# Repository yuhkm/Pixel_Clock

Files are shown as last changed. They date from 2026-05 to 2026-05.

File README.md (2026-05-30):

# PixelClock

An ESP32-S3 smart desk clock based on a NeoPixel LED matrix.
A personal project with self-designed PCB, enclosure CAD, and firmware.

---

<p align="center">
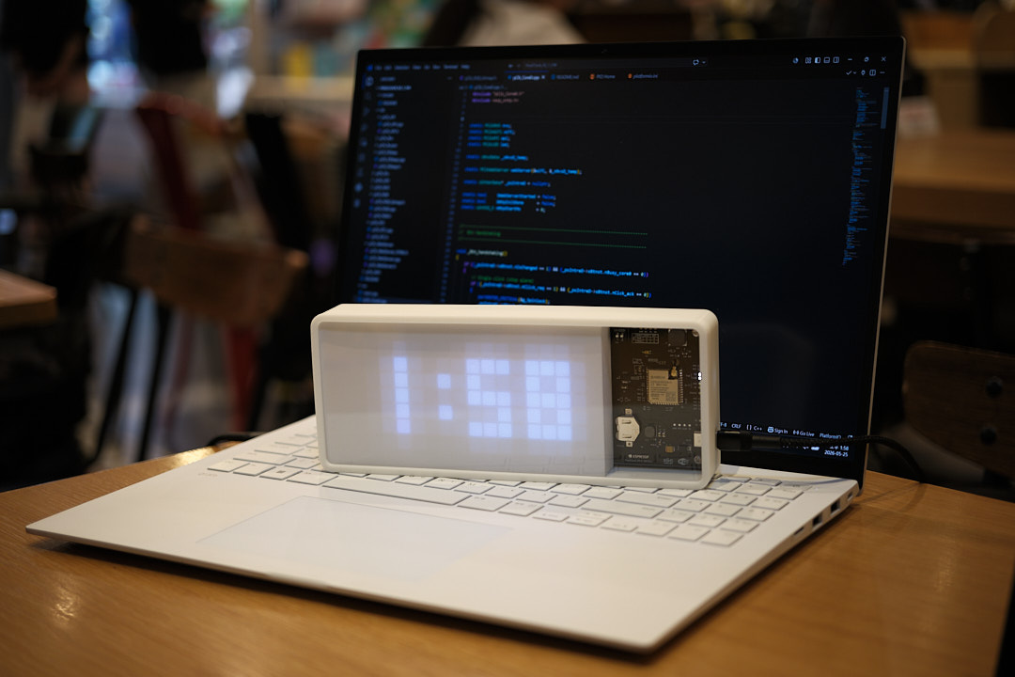
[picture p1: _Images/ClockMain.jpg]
  
  
</p>

<!-- Demo GIF -->
<!-- ![Demo](docs/images/demo.gif) -->

---

## Features

- **Clock** — Automatic NTP time sync, PCF85063A hardware RTC
- **Weather** — KMA ultra-short-term forecast API, displays temperature / sky condition / precipitation
- **Alarm** — Day-of-week repeat alarm with melody and volume control
- **Night Mode** — Auto brightness adjustment via illuminance sensor
- **Sleep Mode** — Auto deep sleep during configured hours, wakes via RTC interrupt
- **Web Setup** — Full configuration through a browser in AP mode

---

## Repository Structure

```
PixelClock/
├── CAD/
│   ├── Type_A/                Enclosure Type A design files
│   └── Type_B/                Enclosure Type B design files
├── FW/
│   ├── src/
│   │   ├── main.cpp           Task creation and entry point
│   │   ├── pClk_Core0.cpp     Core0 state machine (WiFi / NTP / API / Web server)
│   │   └── pClk_Core1.cpp     Core1 state machine (Display / RTC / Alarm)
│   ├── lib/
│   │   ├── pClk_API/          KMA weather API
│   │   ├── pClk_Btn/          Button (click / 3s hold / 10s hold)
│   │   ├── pClk_Buzzer/       Buzzer (beep / melody)
│   │   ├── pClk_DSleep/       Deep sleep entry / wake
│   │   ├── pClk_Illu/         Illuminance sensor ADC
│   │   ├── pClk_LED/          Indicator LEDs
│   │   ├── pClk_NVS/          NVS save / load with CRC verification
│   │   ├── pClk_RGB/          NeoPixel rendering (clock / weather / scroll)
│   │   ├── pClk_RTC/          PCF85063A I2C driver
│   │   ├── pClk_WebServer/    AP setup web server
│   │   └── pClk_WiFi/         WiFi AP / STA management
│   └── include/
│       ├── pClk_config.h      GPIO pin map and parameters
│       └── pClk_gData.h       Inter-core shared data structures
└── PCB/
    ├── Gerber/                Gerber files
    └── SMT/                   SMT files
```

---

## Bill of Materials (BOM)

| Component | Model / Spec |
|---|---|
| MCU | ESPRESSIF ESP32-S3 WROOM-1U N16R8 |
| NeoPixel Matrix | WS2812B 8×8 module × 2 |
| RTC | PCF85063ATT |
| RTC Backup Battery | CR1220 |
| Buzzer | BMB-2703N |
| Illuminance Sensor | TEMT6000 |
| Regulator | AP63203WU |
| Power Connector | USB Type-C |

---

## Hardware

### PCB

| Item | Spec |
|---|---|
| Size | 63×80mm |
| Layers | 4 |
| Design Files | [PCB/](PCB/) |

### Enclosure

| Type | Size | Design Files |
|---|---|---|
| Type A | 217×88×32mm | [CAD/Type_A/](CAD/Type_A/) |
| Type B | 173×88×38mm | [CAD/Type_B/](CAD/Type_B/) |

---

## Software

### Architecture

Runs on FreeRTOS dual-core. Core0 handles networking, Core1 handles display and sensors.

| Core | Role |
|---|---|
| Core 0 | WiFi / NTP / Weather API / Web server |
| Core 1 | NeoPixel matrix / RTC / Illuminance sensor / Button / Buzzer |

---

## Build

**Requirements:** [PlatformIO](https://platformio.org/)

```bash
# Clone the repository
git clone https://github.com/yuhkm/Pixel_Clock.git
cd PixelClock/FW

# Build and upload
pio run --target upload

# Serial monitor
pio device monitor --baud 115200
```

---

## Setup

### Weather API Key Required

To use the weather feature, a **KMA Ultra-Short-Term Forecast API** key is required.

- Get a key: [Korea Public Data Portal - KMA Forecast API](https://www.data.go.kr/data/15084084/openapi.do)
- Enter the key in the API Key field on the setup page

### Setup
1. Hold the button for **3 seconds** to enter setup mode (2 beeps)
2. Connect to the **`PixelClock`** Wi-Fi AP
3. Open **`setup.local`** in a browser
4. Configure WiFi, weather API key, alarm, and display settings, then save
5. Device reboots and applies settings automatically

<p align="center">
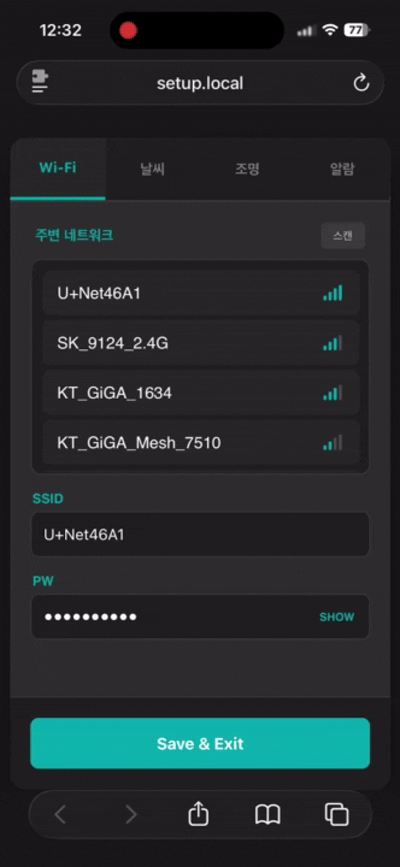
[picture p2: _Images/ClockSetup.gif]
  
</p>

### Factory Reset

Hold the button for **10 seconds** to clear all NVS settings and re-enter setup mode.

---

## Serial Log

Serial monitor format (115200 baud): `>>> [Module][Function] message`

| Tag | Description |
|-----|---|
| `[Core0][BOOT]` | NVS config valid / invalid on boot |
| `[Core0][SETUP]` | Web server started |
| `[Core0][APPLY]` | Config saved, rebooting |
| `[Core0][RESET]` | Factory reset |
| `[WiFi][STA]` | STA connecting / success / failed |
| `[WiFi][AP]` | AP setup complete |
| `[NTP][NTP]` | NTP initialized / received / timeout |
| `[Weather][API]` | Updated / Failed with HTTP code / Parse error |
| `[WEB][HTTP]` | Web server started |
| `[Core1][NVS]` | Settings applied |
| `[Core1][RTC]` | NTP → RTC sync |
| `[Core1][ALARM]` | Alarm fired / auto-stopped |
| `[Core1][ILLU]` | Night mode ON / OFF |
| `[NVS][CRC]` | CRC mismatch (settings cleared) |
| `[RTC][I2C]` | I2C init failed |
| `[DSleep][RTC]` | Entering deep sleep, wake time |

---

## License

[MIT License](LICENSE)

Copyright (c) 2026 <!-- name or GitHub username -->

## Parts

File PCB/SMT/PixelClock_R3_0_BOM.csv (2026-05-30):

Comment | Designator | Footprint
CR1220 | B1 | LIB_CR1220_SMD:LIB_CR1220_SMD
Buzzer | BZ1 | Buzzer_Beeper:MagneticBuzzer_CUI_CMT-8504-100-SMT
100uF(T) | C1 | Capacitor_Tantalum_SMD:CP_EIA-3528-21_Kemet-B
100nF(0402) | C2,C7,C8,C10,C11 | Capacitor_SMD:C_0402_1005Metric
22uF(0805) | C3,C4 | Capacitor_SMD:C_0805_2012Metric
10uF(0805) | C5,C6 | Capacitor_SMD:C_0805_2012Metric
1uF(0603) | C9 | Capacitor_SMD:C_0603_1608Metric
TVS | D1 | Diode_SMD:D_SMB
RB521S30T1G | D2,D3,D4 | Diode_SMD:D_SOD-523
USB_C_Receptacle_USB2.0_16P | J1 | Connector_USB:USB_C_Receptacle_GCT_USB4085
Conn_01x04_Pin | J2 | Connector_PinHeader_2.54mm:PinHeader_1x04_P2.54mm_Vertical
Molex_5268-03_F | J3,J4,J5 | Connector_Molex:Molex_SPOX_5267-03A_1x03_P2.50mm_Vertical
3.9uH | L1 | Inductor_SMD:L_APV_ANR6020
LED_Y | L2,L3,L4,L5,L6,L7 | LED_SMD:LED_0603_1608Metric
SS8050 | Q1 | Package_TO_SOT_SMD:SOT-23
5.1kR(0402) | R1,R2 | Resistor_SMD:R_0402_1005Metric
10kR(0402) | R3,R4,R5,R6,R7,R8,R9,R15,R19,R26 | Resistor_SMD:R_0402_1005Metric
22R(0402) | R10,R11 | Resistor_SMD:R_0402_1005Metric
4.7kR(0402) | R12,R13,R14 | Resistor_SMD:R_0402_1005Metric
1kR(0603) | R16,R17,R18,R20,R23,R24,R25 | Resistor_SMD:R_0603_1608Metric
SW_DIP_x02 | SW1 | Button_Switch_THT:SW_DIP_SPSTx02_Slide_6.7x6.64mm_W7.62mm_P2.54mm_LowProfile
SW_Push | SW2 | Button_Switch_THT:SW_PUSH_6mm
ESP32-S3-WROOM-1 | U1 | RF_Module:ESP32-S3-WROOM-1U
AP63203WU | U2 | Package_TO_SOT_SMD:TSOT-23-6
PCF85063ATT_AJ | U3 | lumina_lib:SOP65P490X110-8N
TEMT6000 | U4 | lumina_lib:TEMT6000
Q13FC13500004 | Y1 | LIB_Q13FC13500004:Q13FC13500004FC13532768KHZ125PF

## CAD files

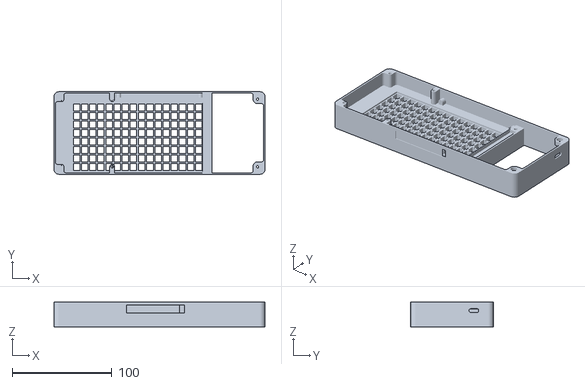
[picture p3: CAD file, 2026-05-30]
CAD/Type_A/PixelClock_Type_A_Middle.STL
212.0 x 83.0 x 25.0

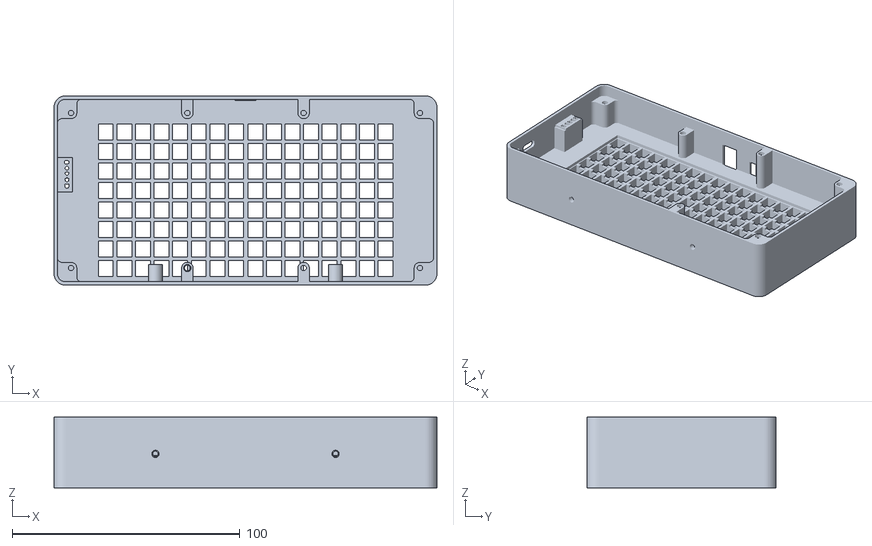
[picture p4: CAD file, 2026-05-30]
CAD/Type_B/PixelClock_Type_B_Middle.STL
168.0 x 83.0 x 31.0

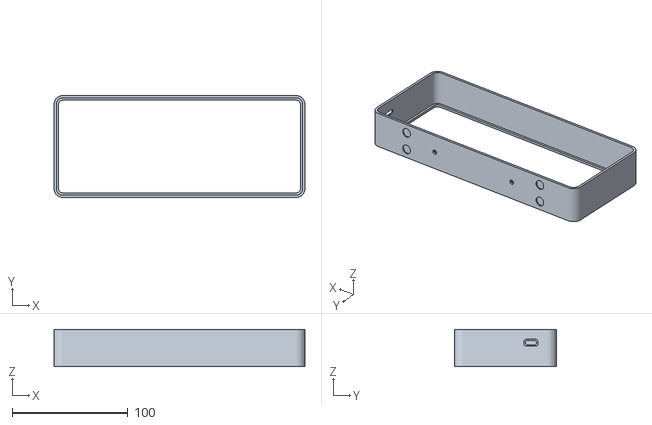
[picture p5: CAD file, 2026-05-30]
CAD/Type_A/PixelClock_Type_A_Front.STL
217.0 x 88.0 x 32.0

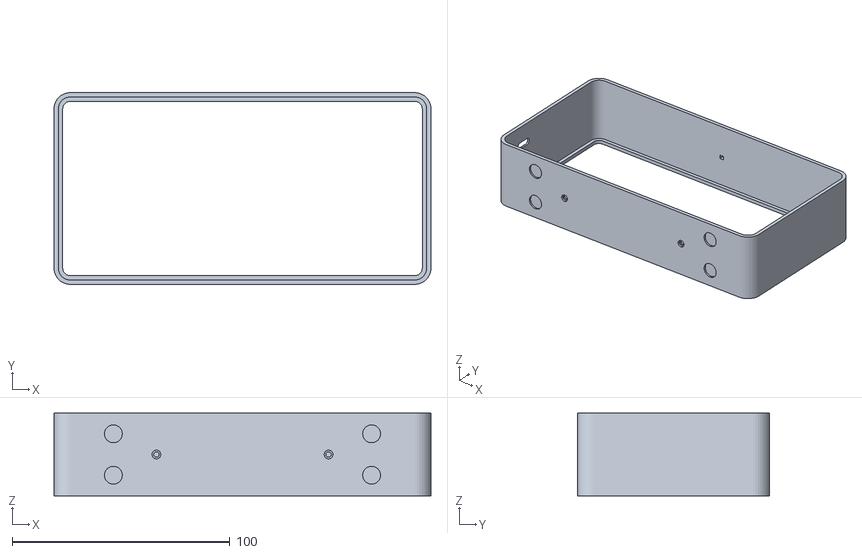
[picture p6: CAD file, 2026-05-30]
CAD/Type_B/PixelClock_Type_B_Front.STL
173.0 x 88.0 x 38.0

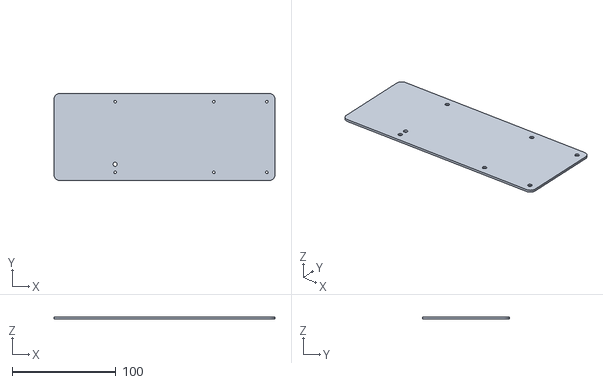
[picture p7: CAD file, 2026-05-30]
CAD/Type_A/PixelClock_Type_A_Back.STL
212.6 x 83.6 x 2.00

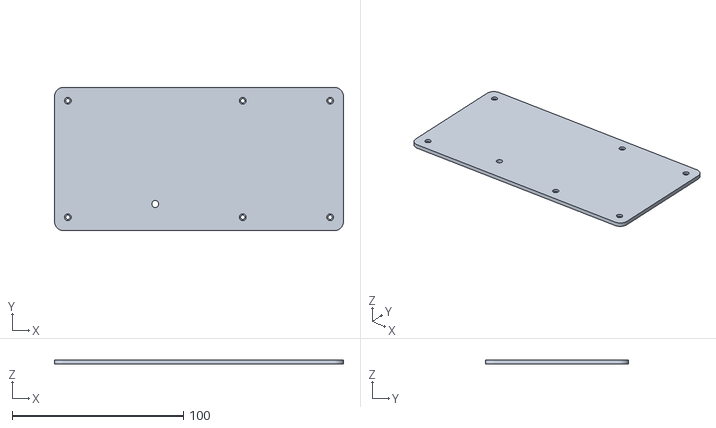
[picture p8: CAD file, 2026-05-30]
CAD/Type_B/PixelClock_Type_B_Back.STL
168.6 x 83.6 x 2.50

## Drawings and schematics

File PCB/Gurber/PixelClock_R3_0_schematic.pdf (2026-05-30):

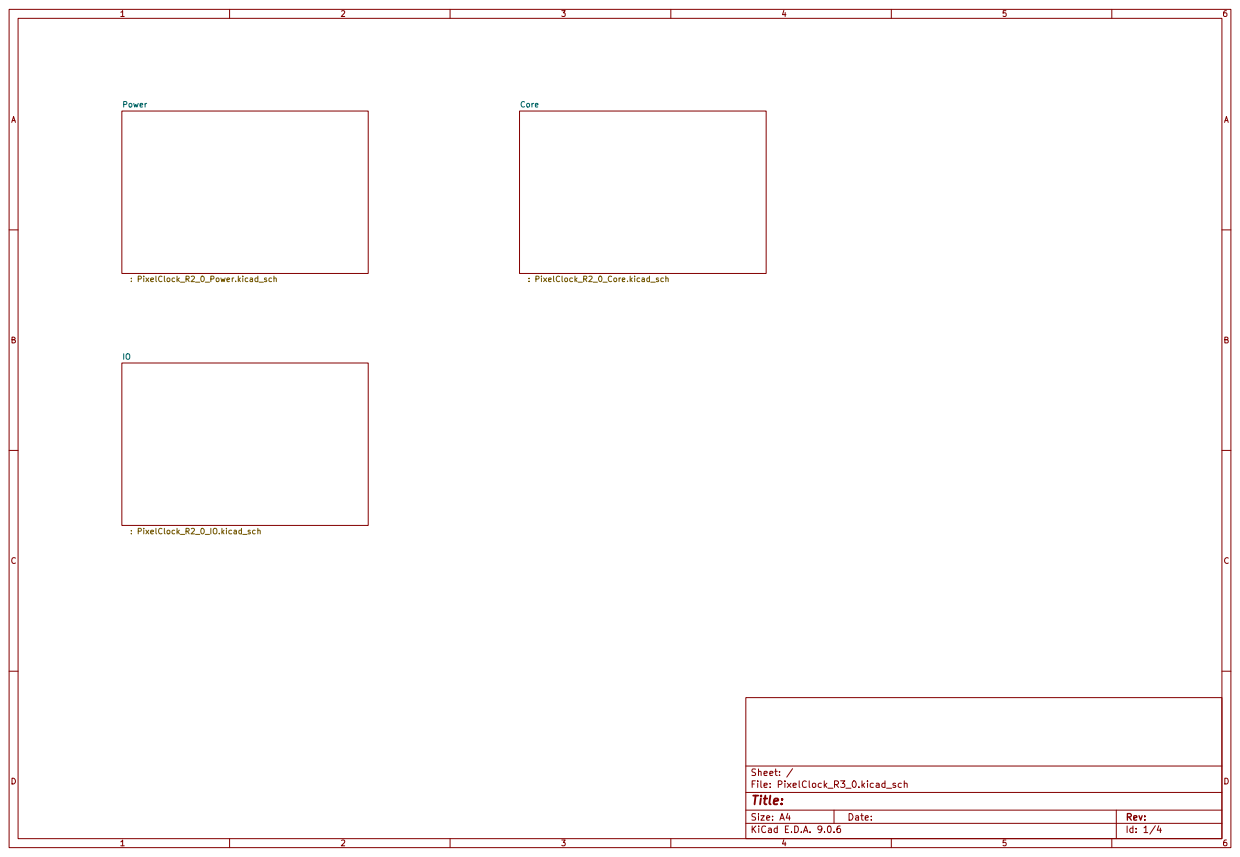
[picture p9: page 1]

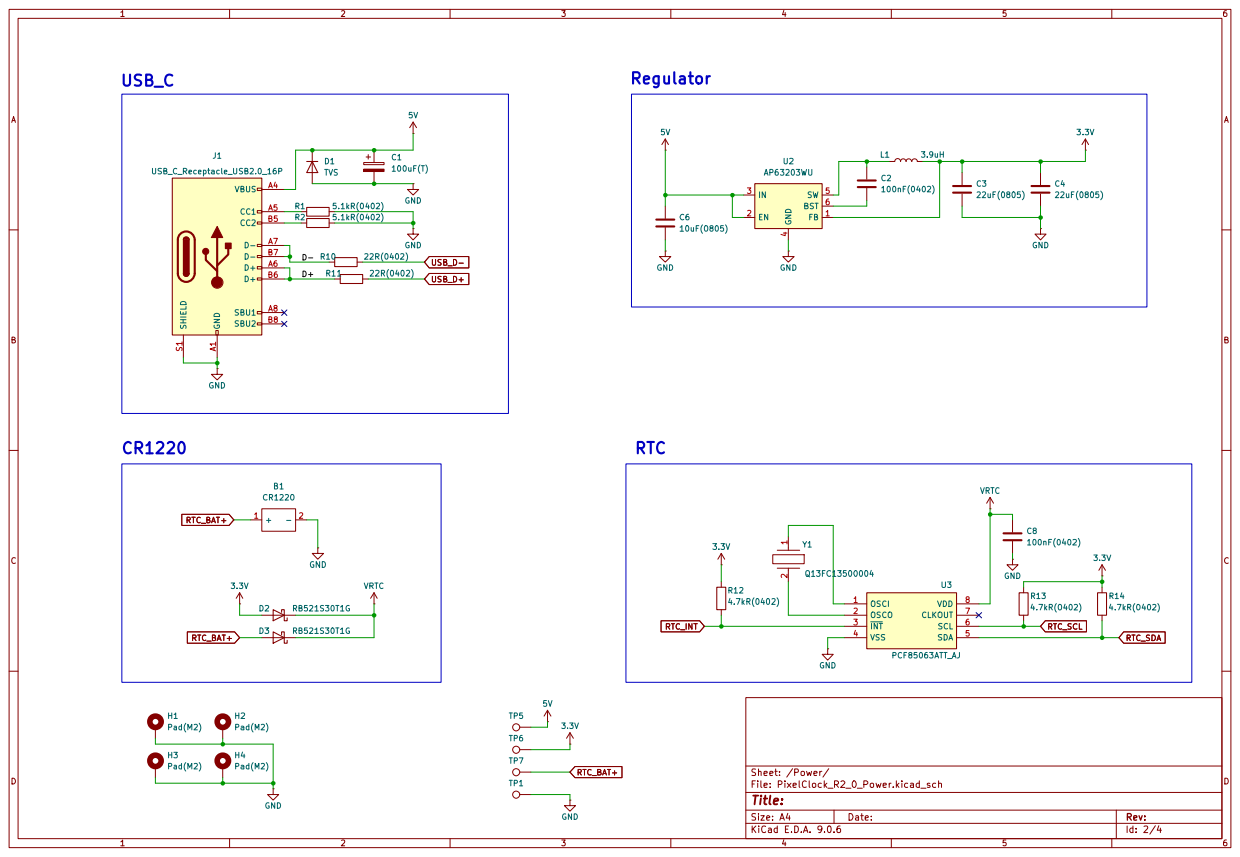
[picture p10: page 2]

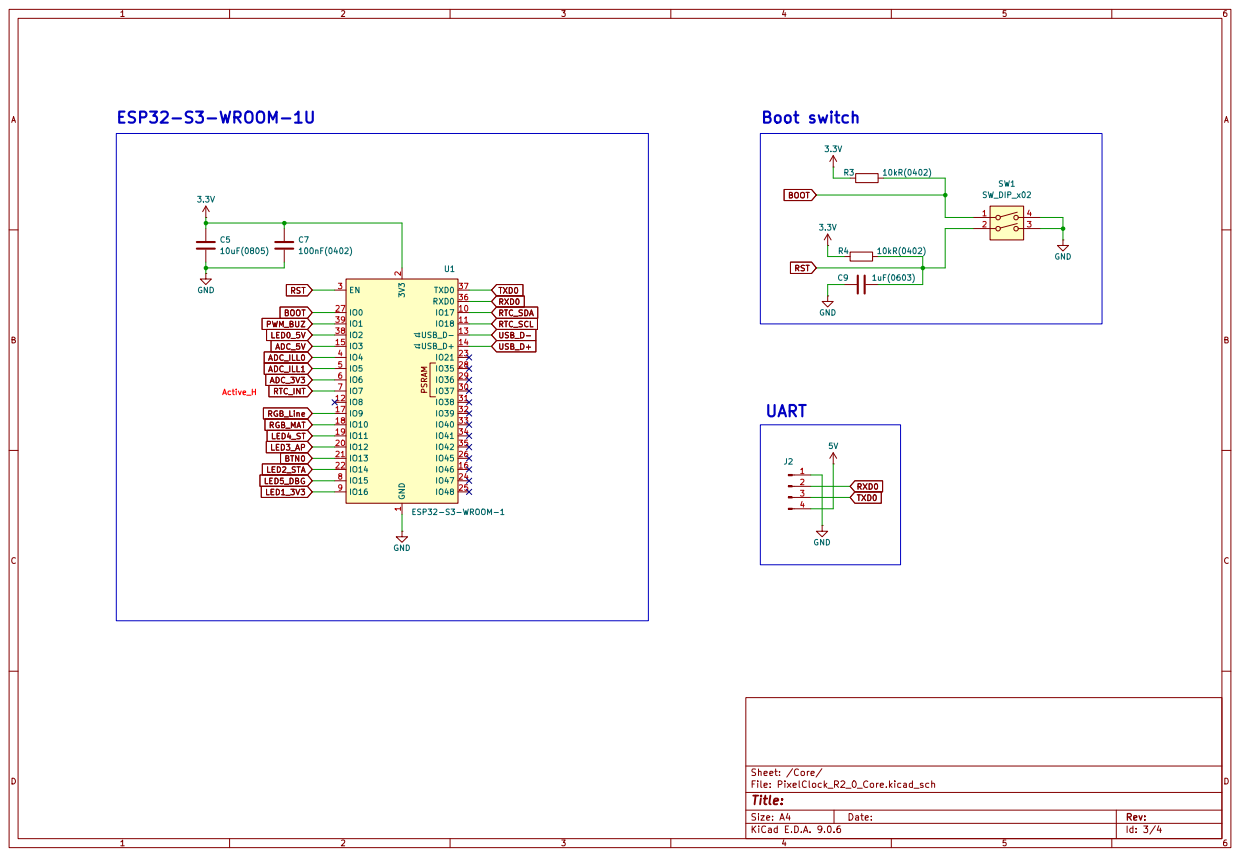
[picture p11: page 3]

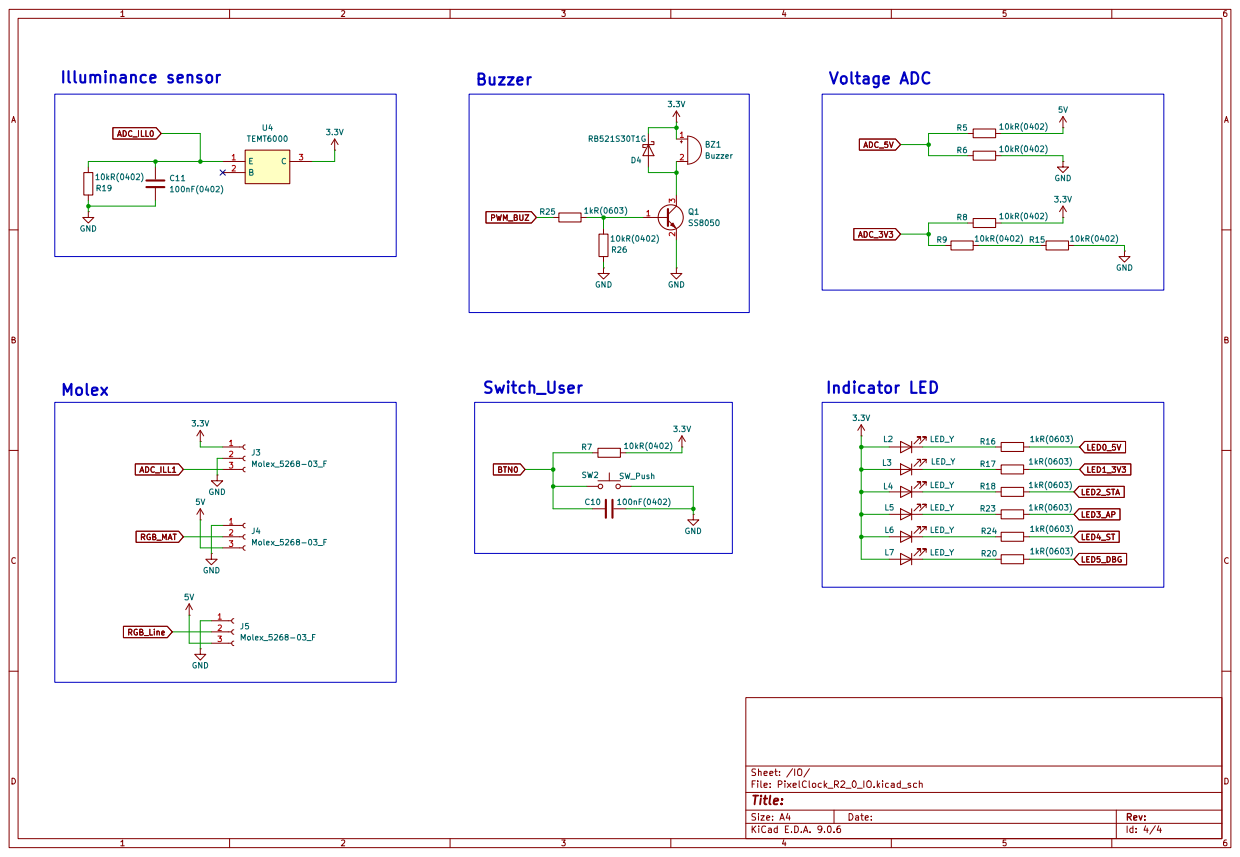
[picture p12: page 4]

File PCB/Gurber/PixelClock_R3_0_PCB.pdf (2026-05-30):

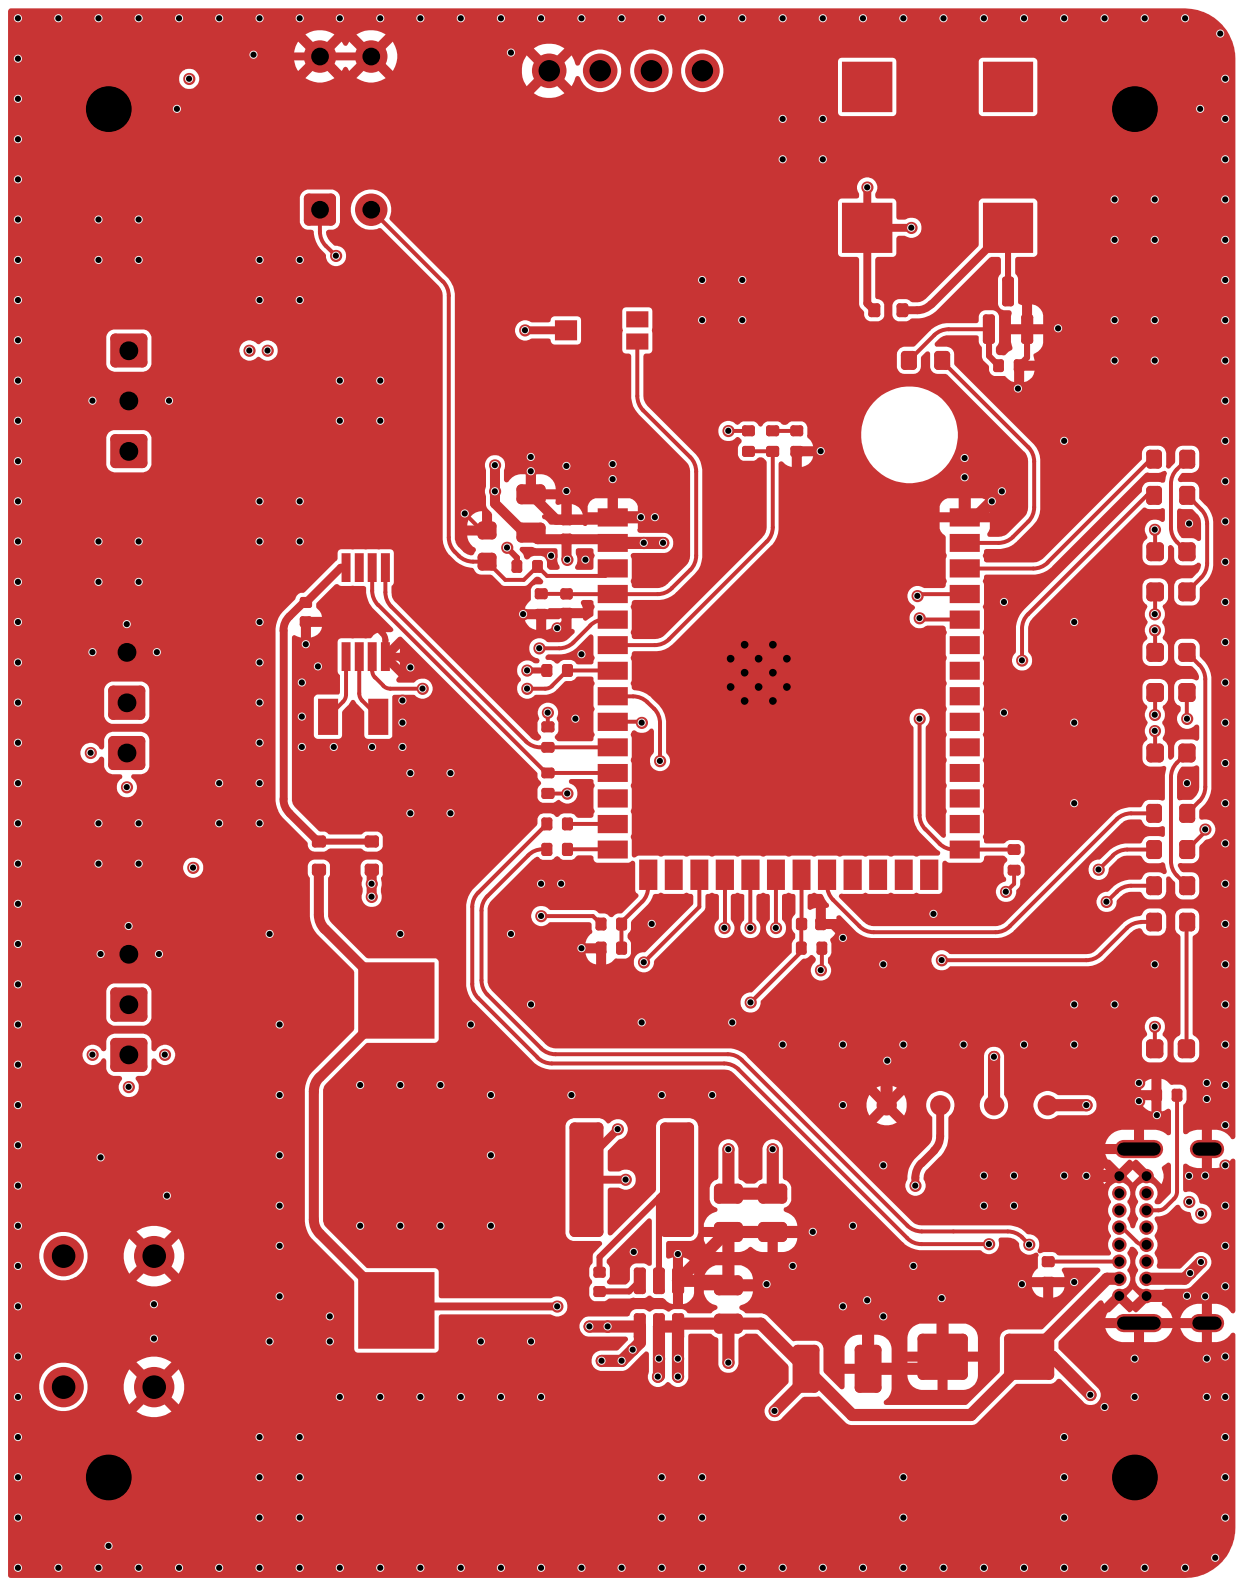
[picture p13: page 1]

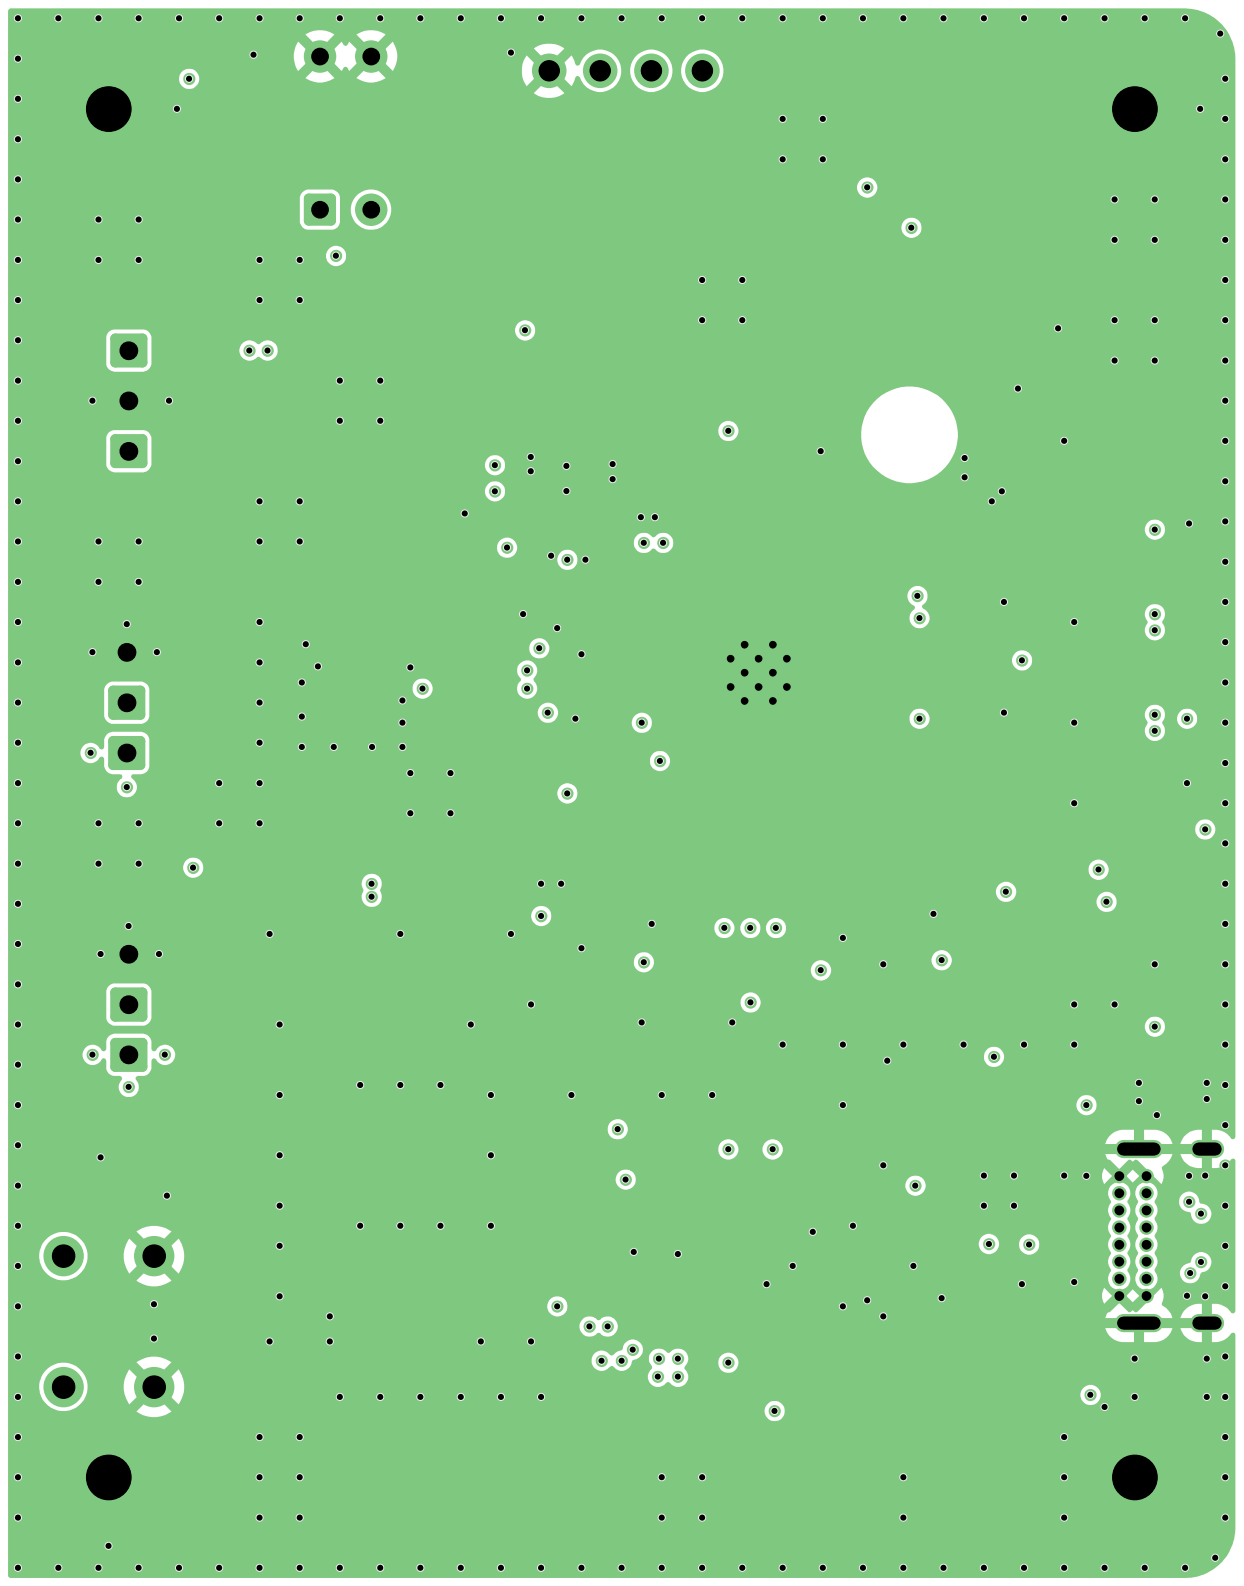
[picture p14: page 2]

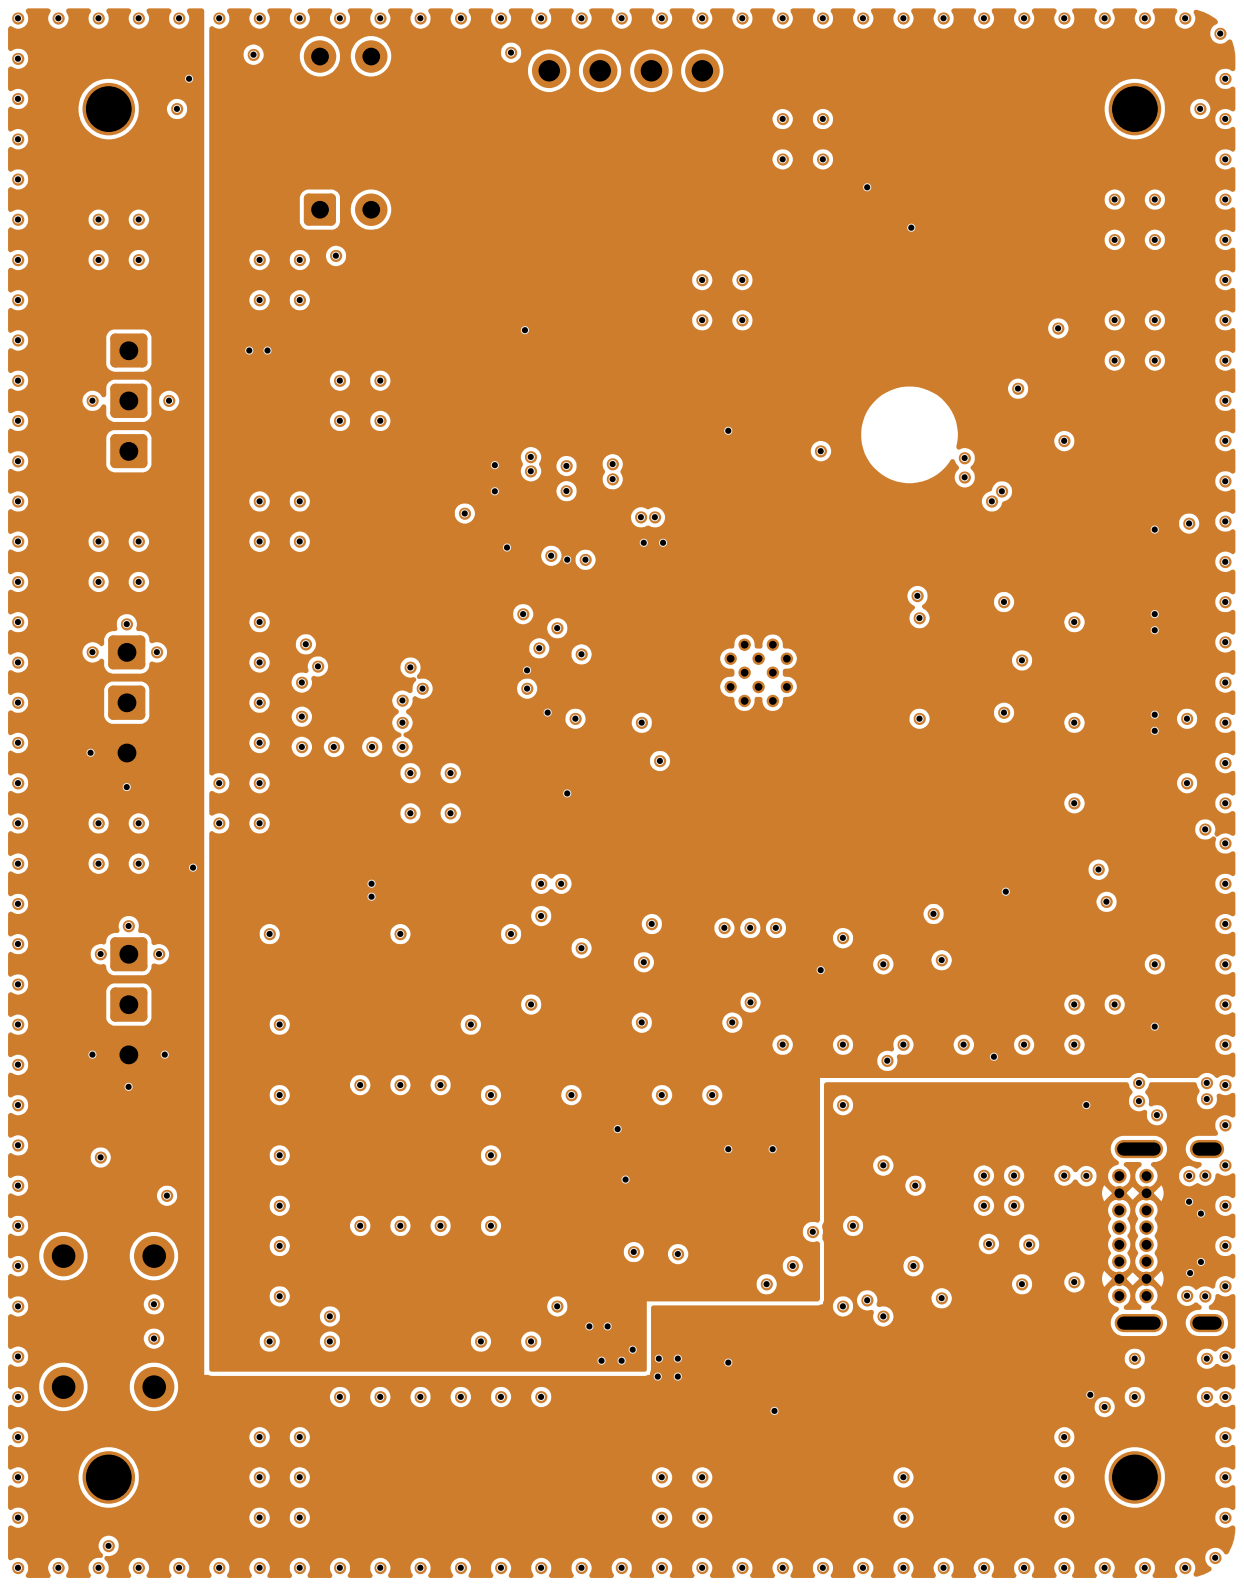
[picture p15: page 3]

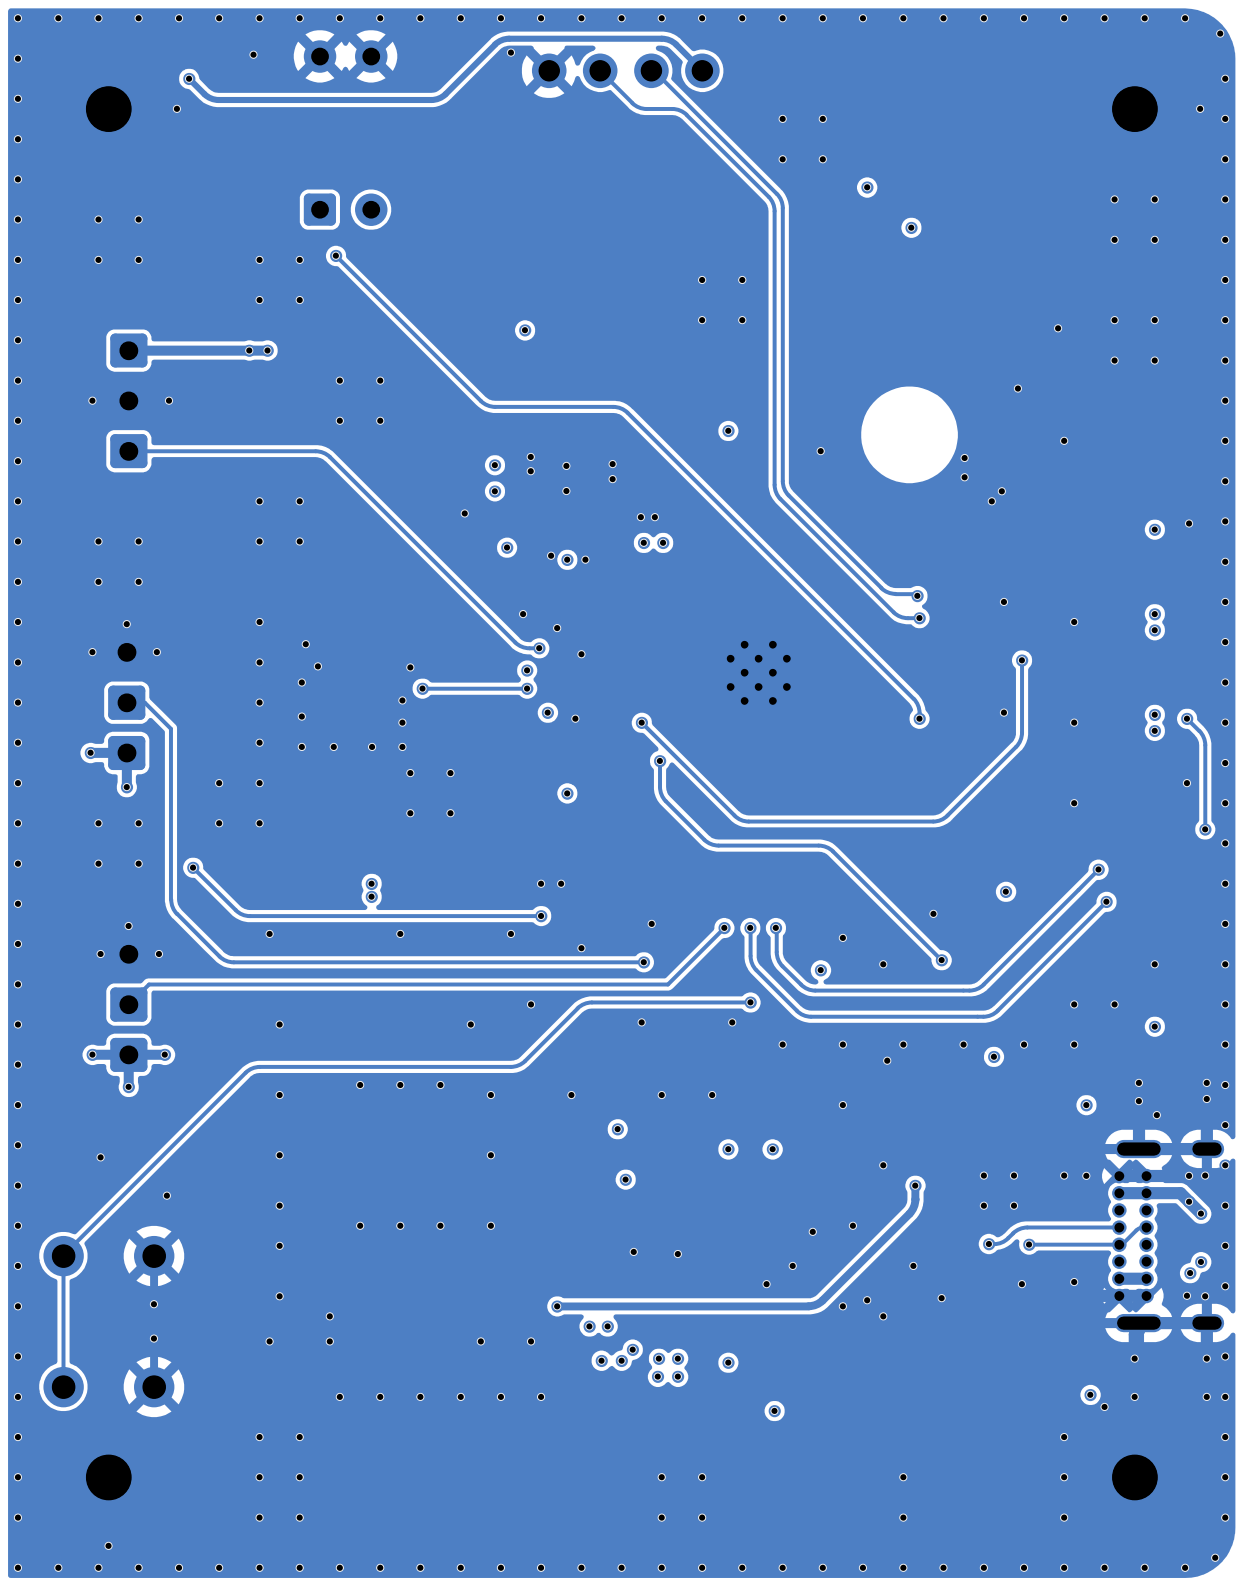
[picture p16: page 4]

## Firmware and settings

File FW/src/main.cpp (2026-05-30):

#include <Arduino.h>
#include "pClk_config.h"

#include "pClk_gData.h"
#include "pClk_Core0.h"
#include "pClk_Core1.h"
#include "pClk_Buzzer.h"
#include "pClk_Buzzer_Alarm.h"



portMUX_TYPE g_Spinlock = portMUX_INITIALIZER_UNLOCKED;

sInterData g_sInterData;


//--------------------------------------------------------------------------------
//  Task Buzzer
//--------------------------------------------------------------------------------

void Task_Buzzer(void *pvParameters)
{
    static PClkBuzzer buzzer;
    buzzer.init();

    for (;;)
    {
        // Button beep request
        if (g_sInterData.sCtrl.nBeep_req == 1)
        {
            portENTER_CRITICAL(&g_Spinlock);
            uint8_t nCount = g_sInterData.sCtrl.nBeep_count;
            uint8_t nVol   = g_sInterData.sCtrl.nBeep_vol;
            g_sInterData.sCtrl.nBeep_req = 0;
            portEXIT_CRITICAL(&g_Spinlock);

            buzzer.beep(nCount, nVol);
        }

        // Melody preview (1 cycle)
        else if (g_sInterData.sCtrl.nPreview_req == 1)
        {
            portENTER_CRITICAL(&g_Spinlock);
            uint8_t nIdx = g_sInterData.sCtrl.nPreview_tone;
            uint8_t nVol = g_sInterData.sCtrl.nVol_preview;
            g_sInterData.sCtrl.nPreview_req = 0;
            portEXIT_CRITICAL(&g_Spinlock);

            if (nIdx >= ALARM_MELODY_COUNT) nIdx = 0;
            buzzer.playMelody(ALARM_MELODIES[nIdx].notes, ALARM_MELODIES[nIdx].len, nVol, nullptr);
        }

        // Alarm melody playback
        else if (g_sInterData.sCtrl.nAlarm_pending == 1)
        {
            uint8_t nIdx = g_sInterData.sNvsD.sAlarm.nToneNum;
            if (nIdx >= ALARM_MELODY_COUNT) nIdx = 0;
            uint8_t nVol = (uint8_t)g_sInterData.sNvsD.sAlarm.nVolume;

            buzzer.playMelody(
                ALARM_MELODIES[nIdx].notes,
                ALARM_MELODIES[nIdx].len,
                nVol,
                &g_sInterData.sCtrl.nAlarm_pending
            );
        }

        else
        {
            vTaskDelay(pdMS_TO_TICKS(50));
        }
    }
}


//--------------------------------------------------------------------------------
//  Task Button
//--------------------------------------------------------------------------------

void Task_Button(void *pvParameters)
{
    init_btn(&g_sInterData);

    for (;;)
    {
        run_btn();
    }
}


//--------------------------------------------------------------------------------
//  Task Core1
//--------------------------------------------------------------------------------

void Task_Core1(void *pvParameters)
{
    for(;;)
    {
        uint32_t nStart = millis();
        Core1_run();
        uint32_t nElapsed = millis() - nStart;

        if (g_sInterData.eSeq_C1 != CORE1_SETUP)
        {
            if (nElapsed < 500)
            {
                vTaskDelay(pdMS_TO_TICKS(500 - nElapsed));
            }
        }
    }
}


//--------------------------------------------------------------------------------
//  Setup
//--------------------------------------------------------------------------------

void setup()
{
    Serial.begin(PCLK_BAUD_RATE);

    Core0_init(&g_sInterData);
    Core1_init(&g_sInterData);

    // Core 1 main task
    xTaskCreatePinnedToCore(Task_Core1, "Task_Core1", 4096, NULL, 1, NULL, 1);

    // Button task (Core 1)
    xTaskCreatePinnedToCore(Task_Button, "BtnTask", 3072, NULL, 2, NULL, 1);

    // Buzzer task (Core 1)
    xTaskCreatePinnedToCore(Task_Buzzer, "BuzzerTask", 2048, NULL, 1, NULL, 1);
}


//--------------------------------------------------------------------------------
//  Loop
//--------------------------------------------------------------------------------

void loop()
{
    core0_run();
    yield();
}

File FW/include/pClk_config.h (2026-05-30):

#ifndef PCLK_CONFIG_H_
#define PCLK_CONFIG_H_



//--------------------------------------------------------------------------------
//  Parameter
//--------------------------------------------------------------------------------

// Serial
#define PCLK_BAUD_RATE              115200

// RGB count
#define RGB_CNT_MAT                 128

// STA active time (triggers every hour)
#define STA_ACTIVE_mm               0
  
// ADC
#define ADC_SAMPLE_PERIOD_MS        3000

// Deep Sleep
#define DSLEEP_PREWAKE_MIN          2

// Alarm auto-stop (5 Min)
#define ALARM_AUTO_STOP_MS          (5UL * 60UL * 1000UL)  

// Weather API retry
#define DSLEEP_WEATHER_RETRY        3

// Buzzer (default beep volume 0~100%)
#define BUZZER_PWM_CH               0
#define BUZZER_BEEP_VOL             5

// Voltage ADC lower, upper limit
#define ADC_5V_MIN                  4.0f
#define ADC_5V_MAX                  6.0f
#define ADC_33V_MIN                 2.8f
#define ADC_33V_MAX                 3.8f

// ADC nonlinear correction factors
#define ADC_5V_CORR                 0.89f
#define ADC_33V_CORR                0.77f


//--------------------------------------------------------------------------------
//  GPIO Pin map
//--------------------------------------------------------------------------------

// Boot
#define GPIO_BOOT                   0

// RTC
#define GPIO_RTC_SDA                17
#define GPIO_RTC_SCL                18
#define GPIO_RTC_INT                7

// RGB
#define GPIO_RGB_MAT                10

// Illuminance
#define GPIO_ILLU_0                 4

// Button
#define GPIO_BTN_0                  13

// Buzzer
#define GPIO_BUZZER                 1

// Voltage ADC
#define GPIO_ADC_5V                 3
#define GPIO_ADC_3V3                6

// Indicator LED
#define GPIO_LED_5V                 2
#define GPIO_LED_3V3                16
#define GPIO_LED_AP                 12
#define GPIO_LED_STA                14
#define GPIO_LED_STATUS             11
#define GPIO_LED_TX                 15



#endif
